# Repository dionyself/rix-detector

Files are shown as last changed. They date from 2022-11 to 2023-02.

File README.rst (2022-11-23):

############
RIX Detector
############

Why another DIY metal detector?

RIX Detector is a Powerful metal detector (Development in progress) that combines awesome technology with a simple design.
Hackable and easy to build using inexpensive components, It opens the doors to novices, 
electronicians and detectorists who want to experiment or try new techniques.

It is built using simple components (logic gates and other passive components) therefore making  simple changes like replacing a gate or a crystal results on interesting behaviour (check the documentation about #rixvariants).

How does it word?
RIX contains two oscillators (1 Xtal OSC + 1 Ring OSC), when the detector coil passes through a metal, the oscillator changes its frequency making the detection possible.

Preview:

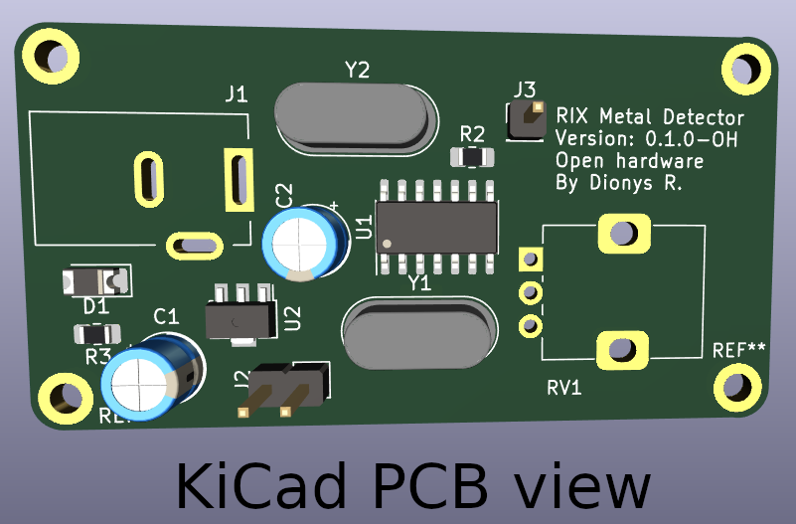
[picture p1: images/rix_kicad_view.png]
KiCad 3Dmodel





   

   
***************
Photos & Videos
***************
<Link to media>

*************
Documentation
*************
<Link to documentation>

***********
Contribute
***********

+------------------------------+
| Donate to this project       |
+-----------+-------+----------+
| Bitcoin   |  XMR  | Paypal   |
+-----------+-------+----------+
| Donate with Bitcoin + Donate with Monero +  +
+-----------+-------+----------+

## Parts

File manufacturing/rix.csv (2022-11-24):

Source: | /home/dionys/workspaces/KiCad/rix-detector/rix/rix.kicad_sch
Date: | Wed 23 Nov 2022 10:49:33 PM AST
Tool: | Eeschema 6.0.9-8da3e8f707~116~ubuntu22.04.1
Generator: | /usr/share/kicad/plugins/bom_csv_grouped_by_value_with_fp.py
Component Count: | 19
Ref | Qnty | Value | Cmp name | Footprint | Description | Vendor
C1, | 1 | 50v 10uF | C_Polarized | Capacitor_THT:CP_Radial_D5.0mm_P2.00mm | Polarized capacitor
C2, | 1 | 50v 1uF | C_Polarized | Capacitor_THT:CP_Radial_D5.0mm_P2.00mm | Polarized capacitor
C3, | 1 | 10nF | C_Small | Capacitor_SMD:C_0805_2012Metric_Pad1.18x1.45mm_HandSolder | Unpolarized capacitor, small symbol
D1, | 1 | LED | LED | Diode_SMD:D_1206_3216Metric_Pad1.42x1.75mm_HandSolder | Light emitting diode
H1, H2, H3, H4, | 4 | MountingHole_Pad | MountingHole_Pad | MountingHole:MountingHole_2.2mm_M2_DIN965_Pad_TopBottom | Mounting Hole with connection
J1, | 1 | Barrel_Jack_Switch | Barrel_Jack_Switch | Connector_BarrelJack:BarrelJack_Kycon_KLDX-0202-xC_Horizontal | DC Barrel Jack with an internal switch
J2, | 1 | Detection coil | Conn_01x02_Male | Connector_PinHeader_2.54mm:PinHeader_1x02_P2.54mm_Vertical | Generic connector, single row, 01x02, script generated (kicad-library-utils/schlib/autogen/connector/)
J3, | 1 | External antenna | Conn_01x01_Male | Connector_PinHeader_2.54mm:PinHeader_1x01_P2.54mm_Vertical | Generic connector, single row, 01x01, script generated (kicad-library-utils/schlib/autogen/connector/)
R1, | 1 | 1M | R | Resistor_SMD:R_0805_2012Metric_Pad1.20x1.40mm_HandSolder | Resistor
R2, | 1 | 1K | R | Resistor_SMD:R_0805_2012Metric_Pad1.20x1.40mm_HandSolder | Resistor
R3, | 1 | 220R | R | Resistor_SMD:R_0805_2012Metric_Pad1.20x1.40mm_HandSolder | Resistor
RV1, | 1 | 10K | R_Potentiometer_MountingPin | Potentiometer_THT:Potentiometer_Alps_RK09K_Single_Vertical | Potentiometer with a mounting pin
U1, | 1 | 74LS04 | 74LS04 | Package_SO:SOIC-14_3.9x8.7mm_P1.27mm | Hex Inverter
U2, | 1 | L78L05_SOT89 | L78L05_SOT89 | Package_TO_SOT_SMD:SOT-89-3 | Positive 100mA 30V Linear Regulator, Fixed Output 5V, SOT-89
Y1, Y2, | 2 | 8.0 Mhz Crystal | Crystal | Crystal:Crystal_HC49-4H_Vertical | Two pin crystal

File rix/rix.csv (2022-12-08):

Source: | /home/dionys/workspaces/KiCad/rix-detector/rix/rix.kicad_sch
Date: | Thu 08 Dec 2022 02:12:27 PM AST
Tool: | Eeschema 6.0.9-8da3e8f707~117~ubuntu22.04.1
Generator: | /usr/share/kicad/plugins/bom_csv_grouped_by_value_with_fp.py
Component Count: | 41
Ref | Qnty | Value | Cmp name | Footprint | Description | Vendor
C1, C2, | 2 | C_Polarized | C_Polarized | Capacitor_THT:CP_Radial_D6.3mm_P2.50mm | Polarized capacitor
C3, C4, | 2 | C_Small | C_Small | Capacitor_THT:C_Disc_D3.8mm_W2.6mm_P2.50mm | Unpolarized capacitor, small symbol
D1, D2, D3, D4, D5, D6, D7, D8, | 8 | LED | LED | LED_THT:LED_D3.0mm | Light emitting diode
H1, H2, H3, H4, H5, | 5 | MountingHole_Pad | MountingHole_Pad | MountingHole:MountingHole_2.2mm_M2_DIN965_Pad_TopBottom | Mounting Hole with connection
J1, J2, | 2 | AudioJack3_SwitchTR | AudioJack3_SwitchTR | Connector_Audio:Jack_3.5mm_Ledino_KB3SPRS_Horizontal | Audio Jack, 3 Poles (Stereo / TRS), Switched TR Poles (Normalling)
J3, | 1 | Conn_01x02_Male | Conn_01x02_Male | Connector_JST:JST_XH_B2B-XH-A_1x02_P2.50mm_Vertical | Generic connector, single row, 01x02, script generated (kicad-library-utils/schlib/autogen/connector/)
J4, | 1 | Barrel_Jack_Switch | Barrel_Jack_Switch | Connector_BarrelJack:BarrelJack_Horizontal | DC Barrel Jack with an internal switch
Q1, | 1 | IRFS4127 | IRFS4127 | Package_TO_SOT_THT:TO-92_Wide | 72A Id, 200V Vds, 18.6mOhm Rds, N-Channel MOSFET, 18.6mOhm Ron, D2PAK
R1, R2, R3, R4, R5, R6, R7, R8, R9, R10, R11, R12, R13, | 13 | R | R | Resistor_THT:R_Axial_DIN0204_L3.6mm_D1.6mm_P5.08mm_Horizontal | Resistor
SW1, | 1 | SW_DIP_x01 | SW_DIP_x01 | Button_Switch_THT:SW_PUSH_6mm_H5mm | 1x DIP Switch, Single Pole Single Throw (SPST) switch, small symbol
SW2, | 1 | SW_Push_DPDT | SW_Push_DPDT | Button_Switch_THT:SW_Push_2P2T_Toggle_CK_PVA2OAH5xxxxxxV2 | Momentary Switch, dual pole double throw
U1, | 1 | 74LS02 | 74LS02 | Package_DIP:DIP-14_W7.62mm | quad 2-input NOR gate
U2, | 1 | L78L05_TO92 | L78L05_TO92 | Package_TO_SOT_THT:TO-92_Wide | Positive 100mA 30V Linear Regulator, Fixed Output 5V, TO-92
U3, | 1 | TL431PK | TL431PK | Package_TO_SOT_THT:TO-92_Wide | Shunt Regulator, SOT-89
Y1, | 1 | Crystal | Crystal | Crystal:Crystal_HC49-4H_Vertical | Two pin crystal

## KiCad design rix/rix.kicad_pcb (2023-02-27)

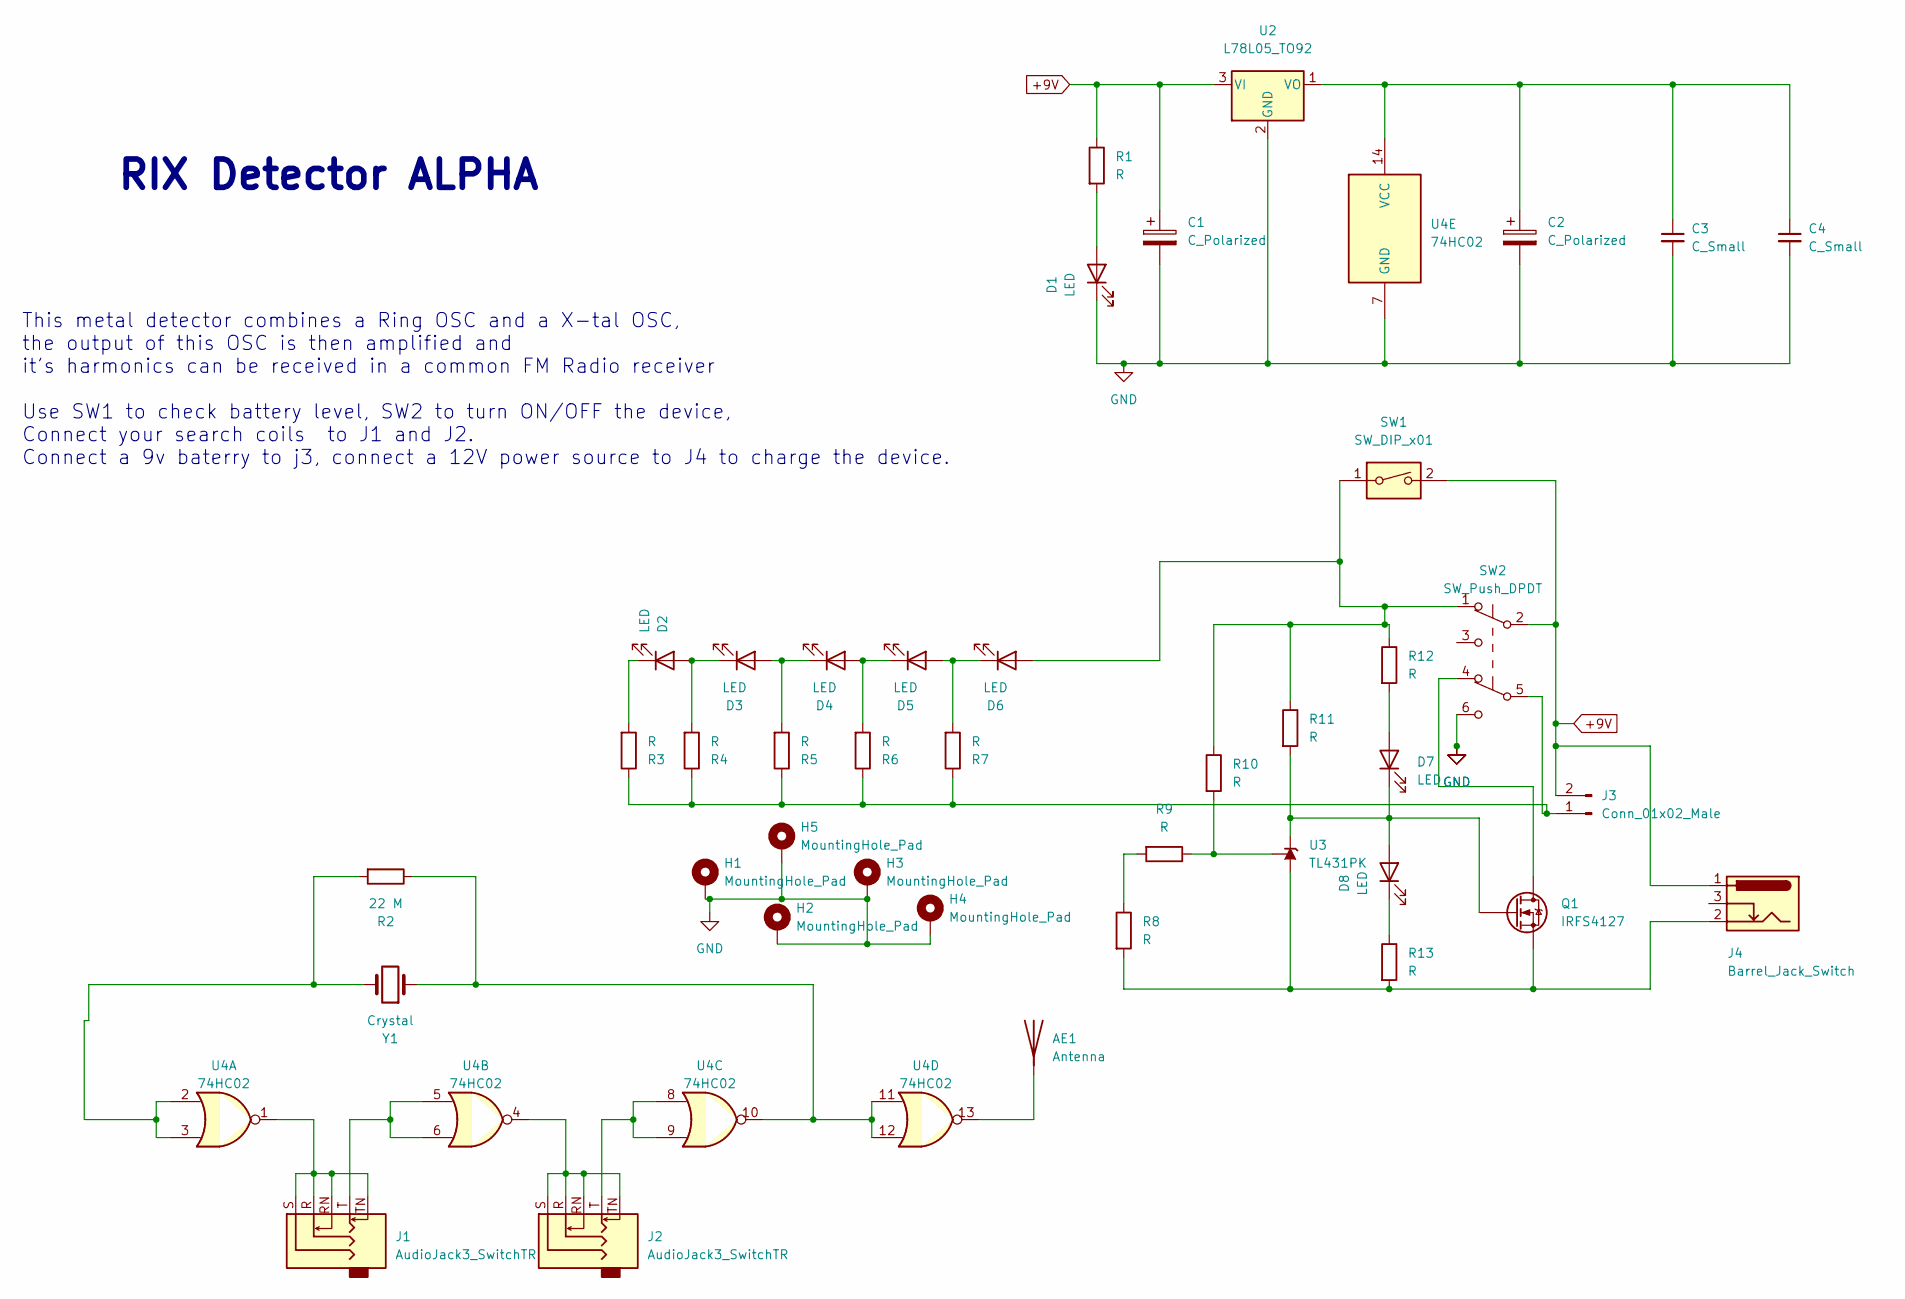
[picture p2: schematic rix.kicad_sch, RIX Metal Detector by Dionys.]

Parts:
AE1: Antenna; PinHeader_1x01_P1.00mm_Vertical
C1, C2: C_Polarized; CP_Radial_D6.3mm_P2.50mm
C3, C4: C_Small; C_Disc_D3.8mm_W2.6mm_P2.50mm
D1, D2, D3, D4, D5, D6, D7, D8: LED; LED_D3.0mm
H1, H2, H3, H4, H5: MountingHole_Pad; MountingHole_2.2mm_M2_DIN965_Pad_TopBottom
J1, J2: AudioJack3_SwitchTR; Jack_3.5mm_Ledino_KB3SPRS_Horizontal
J3: Conn_01x02_Male; JST_XH_B2B-XH-A_1x02_P2.50mm_Vertical
J4: Barrel_Jack_Switch; BarrelJack_Horizontal
Q1: IRFS4127; TO-92_Wide
R1, R3, R4, R5, R6, R7, R8, R9, R10, R11, R12, R13: R; R_Axial_DIN0204_L3.6mm_D1.6mm_P5.08mm_Horizontal
R2: 22 M; R_Axial_DIN0204_L3.6mm_D1.6mm_P5.08mm_Horizontal
SW1: SW_DIP_x01; SW_PUSH_6mm_H5mm
SW2: SW_Push_DPDT; SW_Push_2P2T_Toggle_CK_PVA2OAH5xxxxxxV2
U2: L78L05_TO92; TO-92_Wide
U3: TL431PK; TO-92_Wide
U4: 74HC02; DIP-14_W7.62mm
Y1: Crystal; Crystal_HC49-4H_Vertical

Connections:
+9V: C1.1, J3.2, J4.1, R1.1, SW1.2, SW2.2 (B), U2.3 (VI)
GND: C1.2, C2.2, C3.2, C4.2, D1.1 (K), H1.1, H2.1, H3.1, H4.1, H5.1, SW2.6 (C), U2.2 (GND), U4.7 (GND)
unnamed: AE1.1 (A), U4.13
unnamed: D1.2 (A), R1.2
unnamed: D2.2 (A), D3.1 (K), R4.2
unnamed: D2.1 (K), R3.2
unnamed: D3.2 (A), D4.1 (K), R5.2
unnamed: D4.2 (A), D5.1 (K), R6.2
unnamed: D5.2 (A), D6.1 (K), R7.2
unnamed: D6.2 (A), R10.1, R11.1, R12.1, SW1.1, SW2.1 (A)
unnamed: D7.2 (A), R12.2
unnamed: D7.1 (K), D8.2 (A), Q1.1 (G), R11.2, U3.3 (K)
unnamed: D8.1 (K), R13.1
unnamed: J1.R, J1.RN, J1.S, J1.TN, U4.1
unnamed: J1.T, U4.5, U4.6
unnamed: J2.R, J2.RN, J2.S, J2.TN, U4.4
unnamed: J2.T, U4.8, U4.9
unnamed: J3.1, R3.1, R4.1, R5.1, R6.1, R7.1, SW2.5 (B)
unnamed: Q1.2 (D), SW2.4 (A)
unnamed: J4.2, Q1.3 (S), R8.2, R13.2, U3.2 (A)
unnamed: R2.1, U4.10, U4.11, U4.12, Y1.1
unnamed: R2.2, U4.2, U4.3, Y1.2
unnamed: R8.1, R9.2
unnamed: C2.1, C3.1, C4.1, U2.1 (VO), U4.14 (VCC)
unnamed: R9.1, R10.2, U3.1 (REF)

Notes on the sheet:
This metal detector combines a Ring OSC and a X-tal OSC, the output of this OSC is then amplified and it's harmonics can be received in a common FM Radio receiver Use SW1 to check battery level, SW2 to turn ON/OFF the device, Connect your search coils to J1 and J2. Connect a 9v baterry to j3, conne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
RIX Detector ALPHA

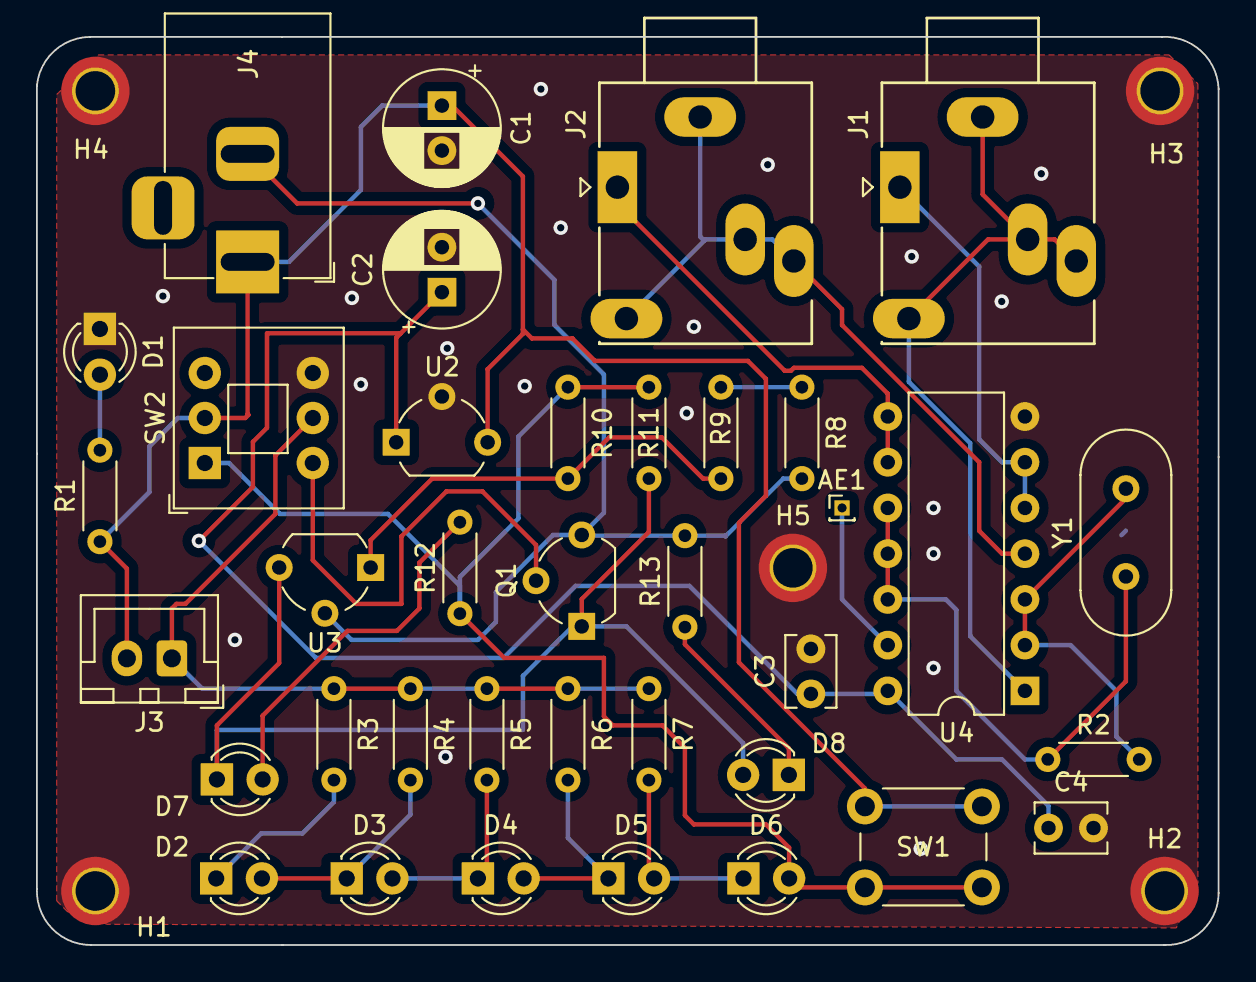
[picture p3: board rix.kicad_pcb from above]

Board: 2 copper layers, 65.7 x 50.5 mm, 42 parts (0 on the bottom side), 25 nets.

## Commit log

2022-11-18 Adding circuit schematics
    [rix.kicad_pcb, rix.kicad_sch]
2022-11-21 PCB improvements
    [rix.csv, rix.kicad_pcb, rix.kicad_sch]
2022-11-22 Adding tracks
    [rix.kicad_pcb]
2022-11-24 Adding gerber files
    [rix-B_Cu.gbr, rix-B_Mask.gbr, rix-B_Paste.gbr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]
2022-11-28 Updating board constraits
    [rix.kicad_pcb, rix.kicad_sch]
2022-12-01 Update gerber files
    [rix-B_Cu.gbr, rix-B_Mask.gbr, rix-B_Paste.gbr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]
2022-12-01 Updating board labels
    [rix.kicad_pcb]
2022-12-08 Updating gerber files
    [rix-B_Cu.gbr, rix-B_Mask.gbr, rix-B_Paste.gbr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]
2023-02-27 Uptating req Kicad7
    [rix.kicad_pcb, rix.kicad_sch]
